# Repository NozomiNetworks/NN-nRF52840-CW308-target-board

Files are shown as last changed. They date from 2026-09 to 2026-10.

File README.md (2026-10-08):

# NN-nRF52840-CW308-target-board

An **open-source hardware design** for a [ChipWhisperer CW308 UFO](https://chipwhisperer.readthedocs.io/en/latest/Targets/CW308%20UFO.html) target board
featuring the [Nordic nRF52840](https://www.nordicsemi.com/Products/nRF52840), a modern ARM Cortex-M4 microcontroller with integrated BLE 5.4
connectivity commonly found in IoT and smart home devices. Designed for **hardware security research**, this board enables researchers and security
professionals to conduct side-channel analysis and fault-injection experiments on real-world IoT targets. The platform facilitates the study of
physical attack vectors against secure microcontrollers, supporting applications such as characterizing clock-glitch windows, analyzing power
consumption patterns, and validating the resilience of cryptographic implementations. Released under the open-source CERN-OHL-S v2 license, this
design empowers the security research community to reproduce, modify, and build upon cutting-edge defense mechanisms for embedded systems.

## Features

- Nordic **nRF52840** SoC (AQFN-73, 7 x 7 mm) — ARM Cortex-M4F @ 64 MHz, BLE 5.4 / 802.15.4 radio
- Standard **CW308 UFO 20-pin** interface (3 x 20-pin headers, J2/J3/J4)
- 32 MHz crystal with solder jumper (**JP1**) to AC-couple the CW308 **CLKIN** signal into the HF clock circuit — useful for clock-glitching experiments
- **CLKOUT** output (12 Ω series) so the target can clock the capture board
- 2.4 GHz radio: **U.FL** antenna connector (J1) with discrete pi-match (3.9 nH + 2 x 1 pF)
- NFC antenna connectors: 2-pin header (J5) and optional 5-pin, 0.5 mm-pitch **FPC** connector (J6)
- CW308 current-shunt sense lines (**SHUNTH**/SHUNTL) routed on-board (R1 = 12 Ω bridge, local decoupling)
- Powered from the CW308 3.3 V rail (VDD and VDDH tied to VCC)
- Standard CW308 form factor: 53.3 x 66.0 mm, 3 x M3 mounting holes

## Signal mapping

| UFO signal | nRF52840 pin | Notes |
|---|---|---|
| SCK | P0.26 | SPI |
| MISO | P0.04 | SPI |
| MOSI | P0.06 | SPI |
| GPIO1_TX | P1.13 | UART TX to CW308 |
| GPIO2_RX | P1.15 | UART RX from CW308 |
| GPIO3 | P0.02 | spare IO |
| GPIO4 | P0.29 | spare IO |
| LED1 | P0.24 | CW308 user LED |
| LED2 | P0.22 | CW308 user LED |
| LED3 | P0.20 | CW308 user LED |
| CLKIN | XC2 (via R2/C20 and JP1) | external clock injection |
| CLKOUT | P1.10 (via R3 = 12 Ω) | target clock to CW308 |
| HDR1 | P0.07 | spare IO |
| HDR2 | P1.09 | spare IO |
| HDR3 | P0.12 | spare IO |
| HDR4 | P0.13 | spare IO |
| HDR5 | P0.15 | spare IO |
| SWDIO | SWDIO | debug |
| SWDCLK | SWDCLK | debug |
| SWO | P1.00 | trace / debug |
| NRST | P0.18 | reset |
| NFC1 | P0.09 / NFC1 | NFC antenna |
| NFC2 | P0.10 / NFC2 | NFC antenna |

Programming and debugging are done through the CW308's onboard programmer (SWD), or by any external SWD adapter connected to the UFO.

## Repository layout

```
├── kicad_project/     KiCad schematic and PCB (nrf52840-ufo)
└── fabrication/       Gerbers, BOM and CPL ready for JLCPCB assembly
```

## Fabrication and assembly

- The files in `fabrication/` are prepared for **JLCPCB** assembly; the BOM includes the corresponding LCSC part numbers (e.g. `C190794` for the nRF52840-QIAA-R).
- The U.FL connector, the 20-pin UFO headers and the NFC pin header are **excluded from assembly** and must be sourced and soldered separately if needed.
- `C13`, `C16` and `C4` are DNP (no-connect placeholders kept for matching/tuning options).

## License

Hardware released under the **CERN Open Hardware Licence Version 2 - Strongly Reciprocal** (CERN-OHL-S-2.0). See [LICENSE](LICENSE).

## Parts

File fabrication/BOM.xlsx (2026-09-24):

Comment | Designator | Footprint | JLCPCB Part #（optional）
2u2 | C1,C5 | Capacitor_SMD:C_0603_1608Metric_Pad1.08x0.95mm_HandSolder | C23630
1u | C2,C12 | Capacitor_SMD:C_0603_1608Metric_Pad1.08x0.95mm_HandSolder | C1592
820pF | C3 | Capacitor_SMD:C_0402_1005Metric_Pad0.74x0.62mm_HandSolder | C107031
100n | C6,C7,C8,C9,C10 | Capacitor_SMD:C_0603_1608Metric_Pad1.08x0.95mm_HandSolder | C14663
100p | C11 | Capacitor_SMD:C_0402_1005Metric_Pad0.74x0.62mm_HandSolder | C1546
1pF | C14,C15 | Capacitor_SMD:C_0402_1005Metric_Pad0.74x0.62mm_HandSolder | C1550
12p | C17,C18 | Capacitor_SMD:C_0402_1005Metric_Pad0.74x0.62mm_HandSolder | C1547
100p | C19,C20 | Capacitor_SMD:C_0603_1608Metric_Pad1.08x0.95mm_HandSolder | C14858
330p | C23,C24 | Capacitor_SMD:C_0603_1608Metric_Pad1.08x0.95mm_HandSolder | C1664
Conn_01x05 | J6 | Connector_FFC-FPC:TE_0-1734839-5_1x05-1MP_P0.5mm_Horizontal | C5162928
3.9nH | L1 | Inductor_SMD:L_0402_1005Metric_Pad0.77x0.64mm_HandSolder | C186836
12R | R1,R2,R3 | Resistor_SMD:R_0603_1608Metric_Pad0.98x0.95mm_HandSolder | C2906990
nRF52840 | U1 | Package_DFN_QFN:Nordic_AQFN-73-1EP_7x7mm_P0.5mm | C190794
Crystal | Y1 | Crystal:Crystal_SMD_3215-2Pin_3.2x1.5mm | C284175

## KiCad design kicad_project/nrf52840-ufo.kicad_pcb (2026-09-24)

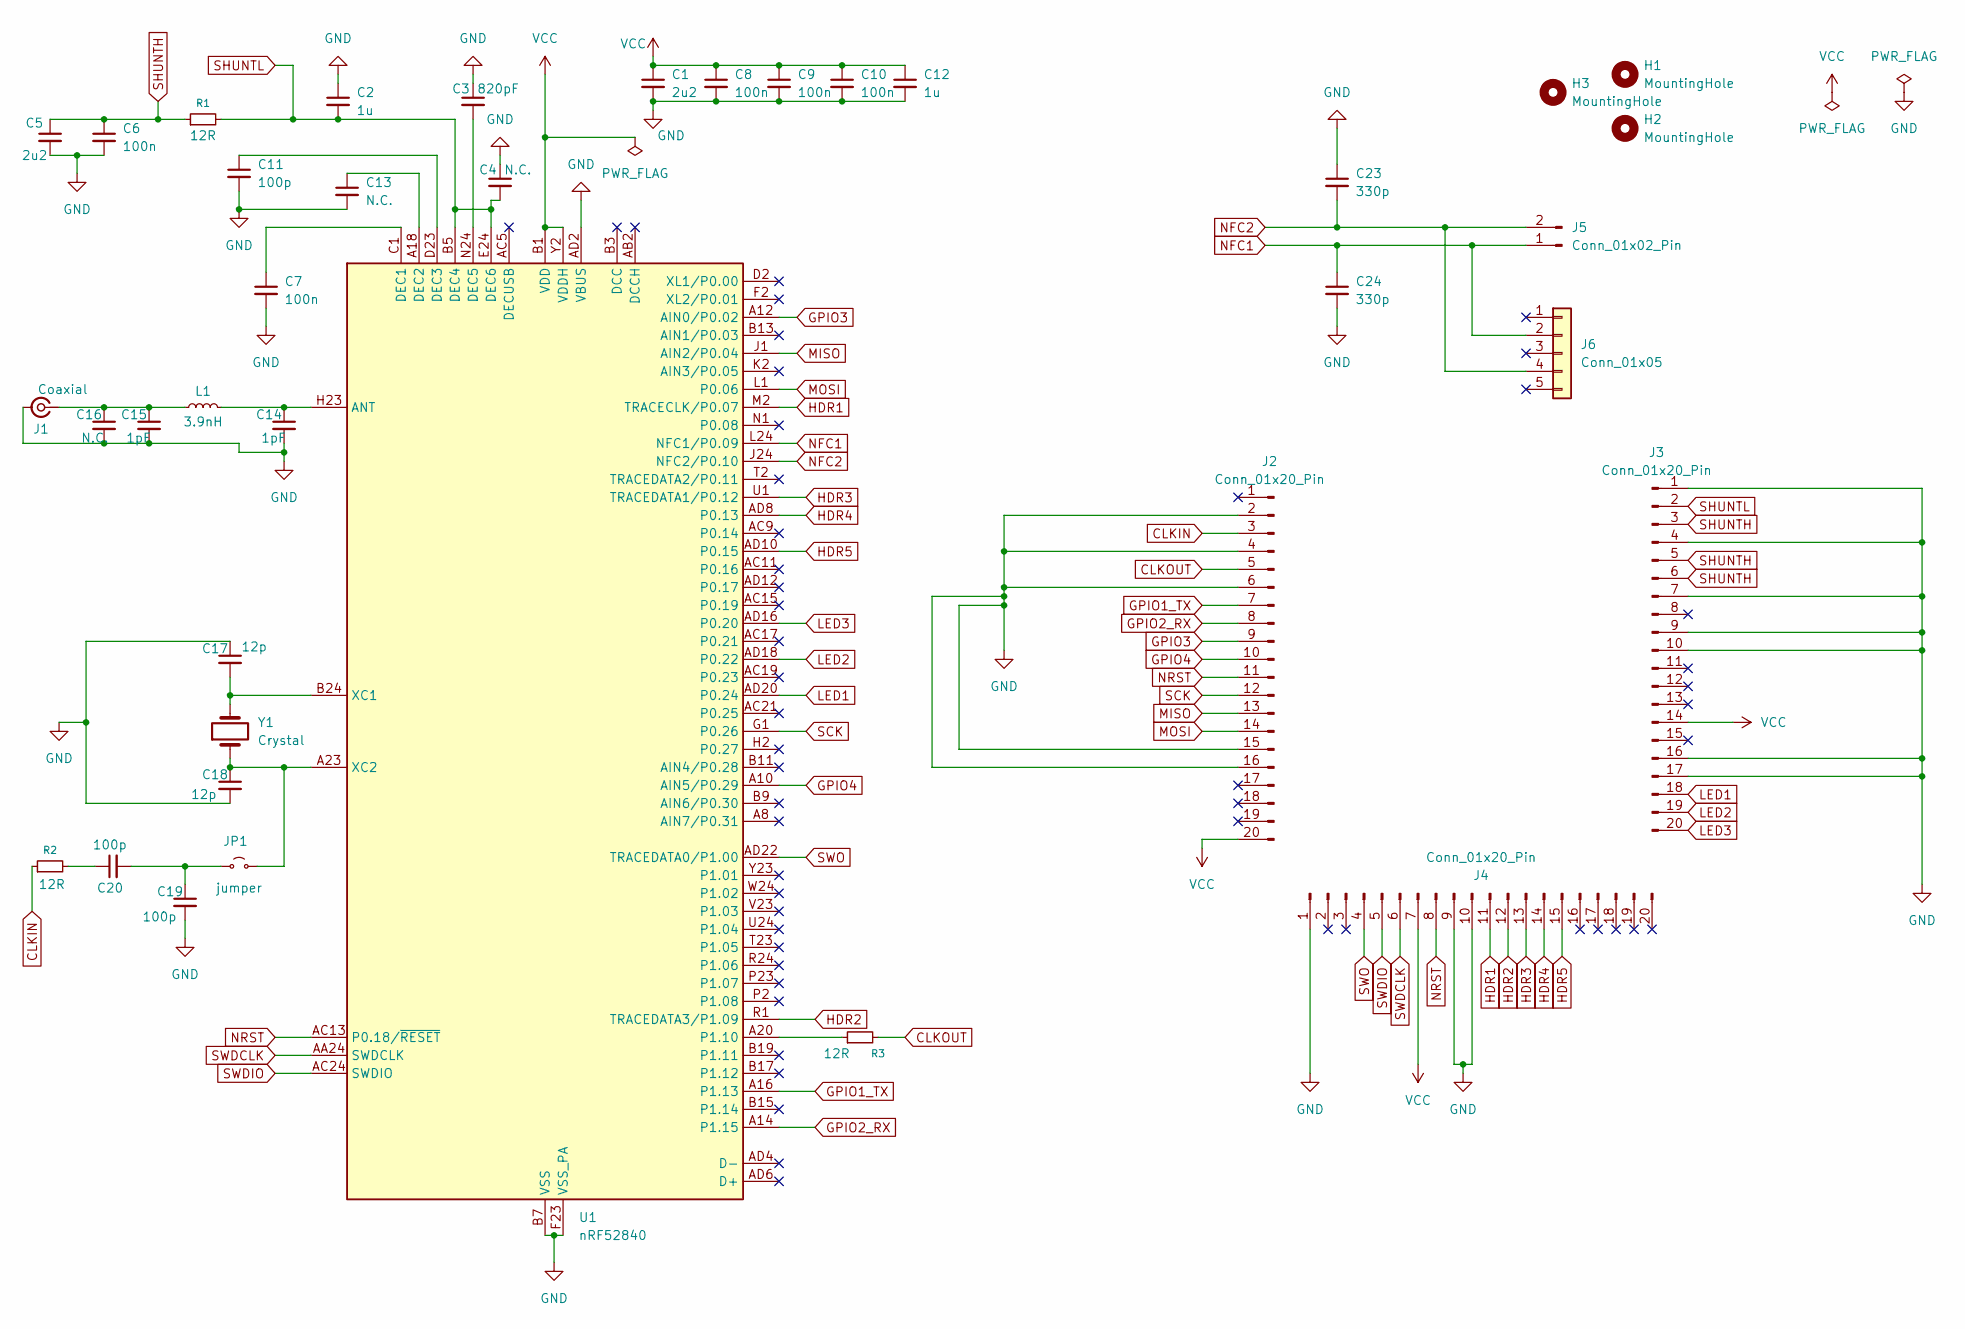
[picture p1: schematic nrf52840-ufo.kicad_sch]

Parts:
C1, C5: 2u2; C_0603_1608Metric_Pad1.08x0.95mm_HandSolder
C2, C12: 1u; C_0603_1608Metric_Pad1.08x0.95mm_HandSolder
C3: 820pF; C_0402_1005Metric_Pad0.74x0.62mm_HandSolder
C4, C13, C16: N.C.; C_0402_1005Metric_Pad0.74x0.62mm_HandSolder
C6, C7, C8, C9, C10: 100n; C_0603_1608Metric_Pad1.08x0.95mm_HandSolder
C11: 100p; C_0402_1005Metric_Pad0.74x0.62mm_HandSolder
C14, C15: 1pF; C_0402_1005Metric_Pad0.74x0.62mm_HandSolder
C17, C18: 12p; C_0402_1005Metric_Pad0.74x0.62mm_HandSolder
C19, C20: 100p; C_0603_1608Metric_Pad1.08x0.95mm_HandSolder
C23, C24: 330p; C_0603_1608Metric_Pad1.08x0.95mm_HandSolder
H1, H2, H3: MountingHole; MountingHole_3.2mm_M3_DIN965_Pad
J1: Coaxial; U.FL_Molex_MCRF_73412-0110_Vertical
J2, J3, J4: Conn_01x20_Pin; PinHeader_1x20_P2.54mm_Vertical
J5: Conn_01x02_Pin; PinHeader_1x02_P2.54mm_Vertical
J6: Conn_01x05; TE_0-1734839-5_1x05-1MP_P0.5mm_Horizontal
JP1: jumper; SolderJumper-2_P1.3mm_Open_RoundedPad1.0x1.5mm
L1: 3.9nH; L_0402_1005Metric_Pad0.77x0.64mm_HandSolder
R1, R2, R3: 12R; R_0603_1608Metric_Pad0.98x0.95mm_HandSolder
U1: nRF52840; Nordic_AQFN-73-1EP_7x7mm_P0.5mm
Y1: Crystal; Crystal_SMD_3215-2Pin_3.2x1.5mm

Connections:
CLKIN: J2.3, R2.1
CLKOUT: J2.5, R3.2
GND: C1.2, C2.1, C3.1, C4.1, C5.2, C6.2, C7.2, C8.2, C9.2, C10.2, C11.2, C12.2, C13.2, C14.2, C15.2, C16.2, C17.1, C18.2, C19.2, C23.1, C24.2, J1.2 (Ext), J2.2, J2.4, J2.6, J2.15, J2.16, J3.1, J3.4, J3.7, J3.9, J3.10, J3.16, J3.17, J4.1, J4.9, J4.10, U1.AD2 (VBUS), U1.B7 (VSS), U1.EP (VSS), U1.F23 (VSS_PA)
GPIO1_TX: J2.7, U1.A16 (P1.13)
GPIO2_RX: J2.8, U1.A14 (P1.15)
GPIO3: J2.9, U1.A12 (AIN0/P0.02)
GPIO4: J2.10, U1.A10 (AIN5/P0.29)
HDR1: J4.11, U1.M2 (TRACECLK/P0.07)
HDR2: J4.12, U1.R1 (TRACEDATA3/P1.09)
HDR3: J4.13, U1.U1 (TRACEDATA1/P0.12)
HDR4: J4.14, U1.AD8 (P0.13)
HDR5: J4.15, U1.AD10 (P0.15)
LED1: J3.18, U1.AD20 (P0.24)
LED2: J3.19, U1.AD18 (P0.22)
LED3: J3.20, U1.AD16 (P0.20)
MISO: J2.13, U1.J1 (AIN2/P0.04)
MOSI: J2.14, U1.L1 (P0.06)
NFC1: C24.1, J5.1, J6.2, U1.L24 (NFC1/P0.09)
NFC2: C23.2, J5.2, J6.4, U1.J24 (NFC2/P0.10)
NRST: J2.11, J4.8, U1.AC13 (P0.18/~RESET)
unnamed: C20.1, R2.2
unnamed: C15.1, C16.1, J1.1 (In), L1.1
unnamed: C19.1, C20.2, JP1.1 (A)
unnamed: C18.1, JP1.2 (B), U1.A23 (XC2), Y1.1
unnamed: C14.1, L1.2, U1.H23 (ANT)
unnamed: C7.1, U1.C1 (DEC1)
unnamed: C13.1, U1.A18 (DEC2)
unnamed: C11.1, U1.D23 (DEC3)
unnamed: C3.2, U1.N24 (DEC5)
unnamed: R3.1, U1.A20 (P1.10)
unnamed: C17.2, U1.B24 (XC1), Y1.2
SCK: J2.12, U1.G1 (P0.26)
SHUNTH: C5.1, C6.1, J3.3, J3.5, J3.6, R1.1
SHUNTL: C2.2, C4.2, J3.2, R1.2, U1.B5 (DEC4), U1.E24 (DEC6)
SWDCLK: J4.6, U1.AA24 (SWDCLK)
SWDIO: J4.5, U1.AC24 (SWDIO)
SWO: J4.4, U1.AD22 (TRACEDATA0/P1.00)
VCC: C1.1, C8.1, C9.1, C10.1, C12.1, J2.20, J3.14, J4.7, U1.A22 (VDD), U1.AD14 (VDD), U1.AD23 (VDD), U1.B1 (VDD), U1.W1 (VDD), U1.Y2 (VDDH)

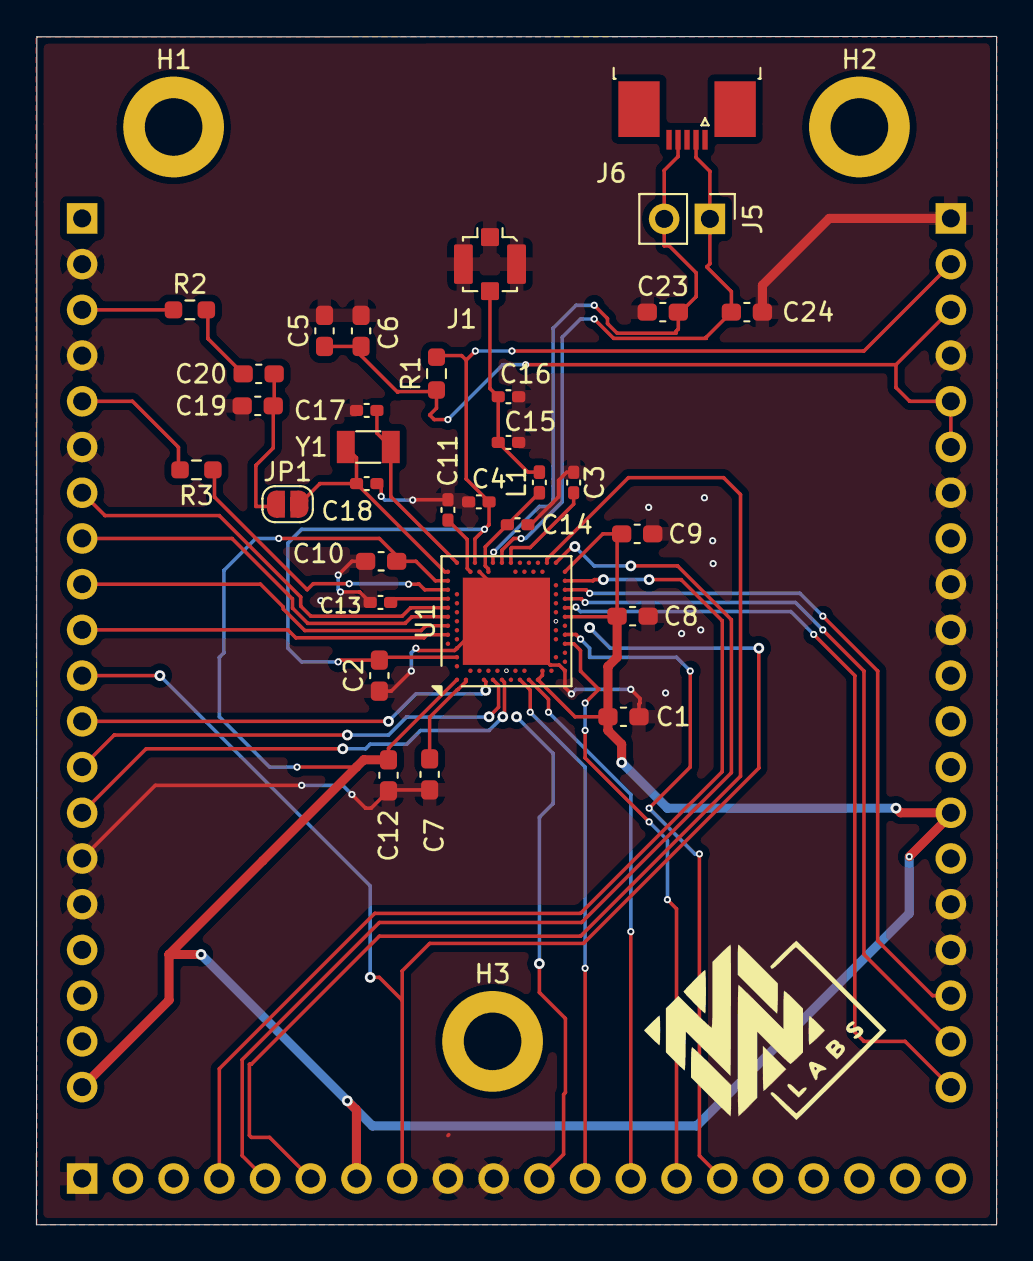
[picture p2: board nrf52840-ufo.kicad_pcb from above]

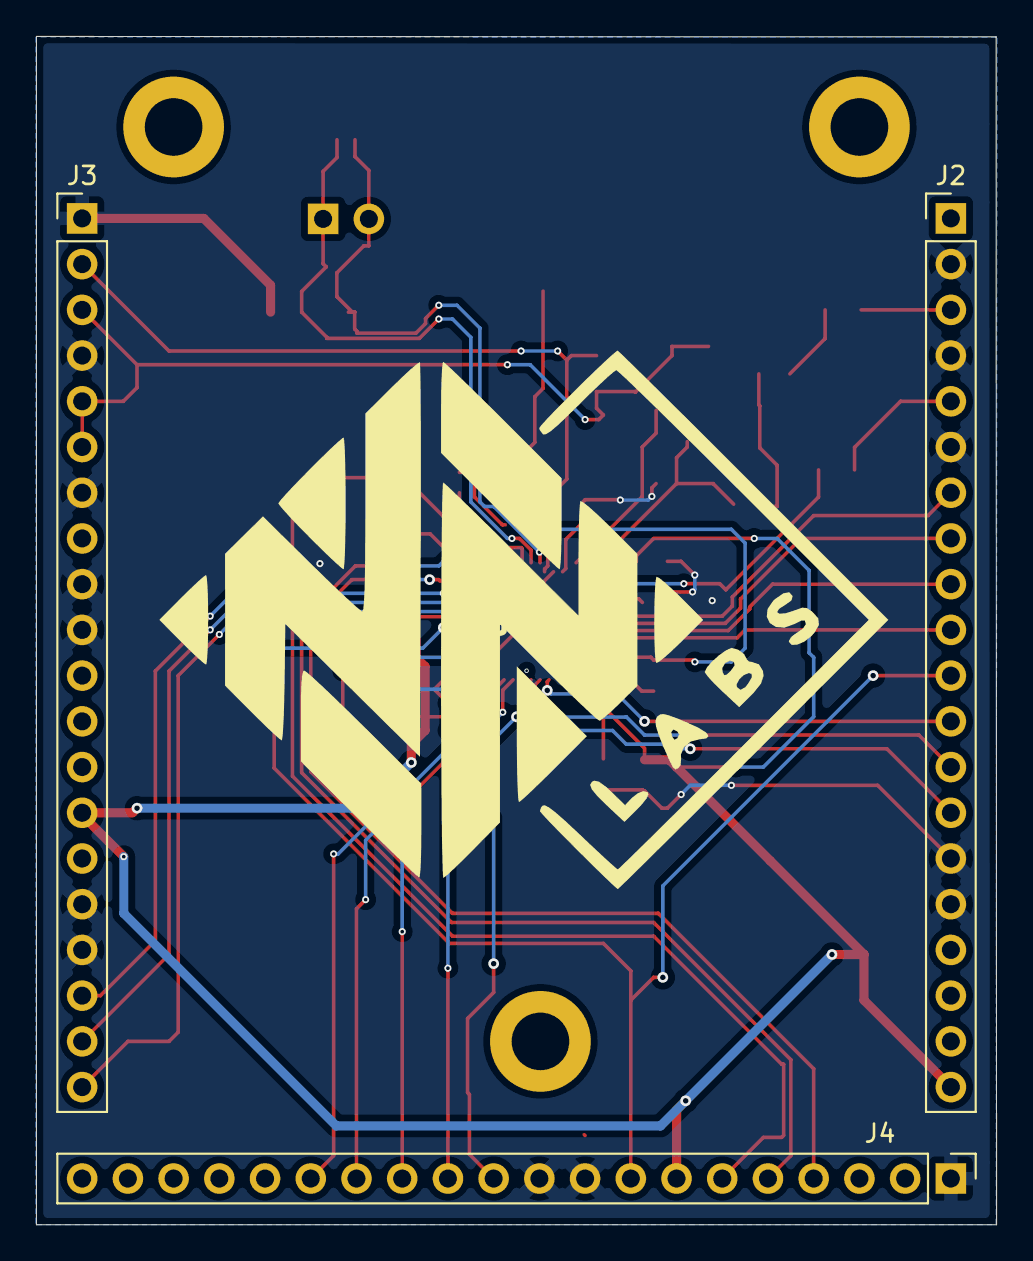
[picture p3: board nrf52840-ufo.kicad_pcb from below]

Board: 4 copper layers, 53.3 x 66.0 mm, 38 parts (3 on the bottom side), 38 nets.
